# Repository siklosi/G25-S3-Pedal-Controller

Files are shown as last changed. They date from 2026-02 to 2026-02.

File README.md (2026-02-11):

# G25 S3 Pedal Controller

<p align="center">


pedal_final
pedal_final
</p>

A modern ESP32-S3 based USB game controller for Logitech G25 pedals featuring web-based configuration, custom response curves, and profile management.

## ✨ Features

- **USB HID Game Controller** - Works as a native joystick with 3 axes (Gas/Brake/Clutch)
- **Web-Based Configuration** - Modern, responsive interface accessible via WiFi
- **Real-Time Monitoring** - Live pedal position visualization with raw and processed values
- **Live Configuration** - All settings (deadzones, curves, smoothing) are applied instantly in RAM for real-time tuning
- **Persistent Storage** - Explicit "Save to Flash" required to store settings permanently across reboots
- **Custom Response Curves** - 11-point adjustable curves with visual editor
- **Curve Presets** - Linear, Progressive, S-Shape, and Aggressive profiles
- **Custom Curve Slots** - Save up to 4 custom curves per pedal
- **Profile Management** - Save/load complete configurations with device storage
- **Profile Import/Export** - Backup configurations to PC as JSON files
- **Advanced Calibration** - Min/max calibration, deadzone control, axis inversion
- **Smoothing & Limiting** - Configurable output smoothing and ceiling adjustments
- **WiFiManager** - Easy WiFi setup with captive portal
- **WebSocket Live Data** - 20Hz real-time pedal data streaming

## 🛠️ Hardware Requirements

### ESP32-S3 Board
- **Board**: ESP32-S3-DevKitC-1 (or compatible)
- **Flash**: 8MB minimum (N8 or N16 variants) with custom partition table
- **PSRAM**: Optional (not required for this project)
- **USB**: Native USB support required

### Hall Effect Sensors
- **Type**: Analog hall effect sensors (e.g., SS49E, A3144, or similar)
- **Quantity**: 3 sensors (one per pedal)
- **Output**: Analog voltage output (0-3.3V)

### Wiring
Connect hall sensors to the following GPIO pins:

| Pedal | GPIO Pin | Color Code (Typical) |
|---|---|---|
| Throttle| GPIO 4 | Green |
| Brake | GPIO 5 | Red |
| Clutch  | GPIO 6 | Blue |

**Power Supply:**
- Sensor VCC → 3.3V
- Sensor GND → GND
- Sensor OUT → GPIO pins above

## 📋 Software Requirements

### PlatformIO
This project uses PlatformIO for building and uploading firmware.

**Install PlatformIO:**
```bash
# VS Code Extension (recommended)
# Install PlatformIO IDE extension from VS Code marketplace

# Or CLI
pip install platformio
```

### Dependencies
All dependencies are managed automatically via `platformio.ini`:
- ArduinoJson 6.21.3
- WebSockets 2.4.1
- WiFiManager 2.0.17
- Joystick_ESP32S2 0.9.4

## 🚀 Installation

### 1. Clone Repository
```bash
git clone https://github.com/yourusername/g25-s3-pedals.git
cd g25-s3-pedals
```

### 2. Upload Filesystem (Web Interface)
```bash
# Upload LittleFS filesystem containing web interface
pio run --target uploadfs
```

### 3. Build and Upload Firmware
```bash
# Build and upload firmware
pio run --target upload
```

### 4. Monitor Serial Output
```bash
# View serial output for debugging
pio device monitor
```

## 📡 WiFi Setup

### First-Time Setup
1. **Power on the ESP32-S3** - It will create a WiFi access point
2. **Connect to AP** - Network name: `G25_S3_Pedals`
3. **Configure WiFi** - Your device should open a captive portal automatically
   - If not, navigate to `192.168.4.1`
4. **Enter credentials** - Select your WiFi network and enter password
5. **Connect** - Device will restart and connect to your network

### Finding Device IP
Check serial monitor output after boot:
```
WiFi Connected!
IP: 192.168.1.xxx
```

Or check your router's DHCP client list for "G25_S3_Pedals"

## 🎮 Usage

### Accessing Web Interface

1. Open browser and navigate to: `http://[ESP32_IP_ADDRESS]`
2. You should see the G25 S3 configuration interface
3. WebSocket connection indicator should show "Connected" (green dot)

### Calibration

#### Quick Calibration
1. **Release all pedals** completely
2. Click **Min** button for each pedal
3. **Press each pedal fully**
4. Click **Max** button for each pedal
5. **IMPORTANT:** Click **Save All to Flash** to perform a permanent save. Live changes are RAM-only.

#### Advanced Options
- **Inverted** - Reverse pedal direction if sensor is mounted backwards
- **Deadzones** - Set start/end deadzones to eliminate jitter
  - *Start*: Adds margin to Min value (ignores initial press)
  - *End*: Subtracts margin from Max value (reaches 100% earlier)
- **Smoothing** - Apply exponential smoothing (0-95%)
- **Output Limit** - Cap maximum output (useful for brake pedal)

### Response Curves

#### Curve Editor
- Click directly on the chart to adjust curve points
- 11 adjustable points from 0% to 100% input
- Real-time preview with live pedal position indicator (red dot) that follows the curve

#### Presets
- **Linear** - 1:1 response (default)
- **Progressive** - Gradual increase, sensitive at start
- **S-Shape** - Smooth acceleration/deceleration
- **Aggressive** - Quick response, less precision

#### Custom Curves
1. Adjust curve to your preference
2. **Hold Shift + Click** "Custom X" button to save
3. Click button (without Shift) to load saved curve
4. Up to 4 custom curves per pedal

### Profile Management

#### Device Profiles (Stored on ESP32)
- **Save** - Enter name and click "Save" to store current configuration
- **Load** - Select profile from list and click "Load Selected"
- **Delete** - Select profile and click "Delete"

#### PC Backup/Restore
- **Export File** - Download current configuration as JSON
- **Import File** - Upload previously exported configuration

### Testing in Games

1. **Windows**: Device appears as "Custom Sim - G25 S3 Pedals"
2. **Check Device Manager** → Human Interface Devices
3. **Test in Game Controller Settings**:
   - Right-click Start → Settings → Devices → Printers & Scanners
   - Or search "Set up USB game controllers"
4. **Verify axes**:
   - X-Axis: Throttle
   - Y-Axis: Brake
   - Z-Axis: Clutch

## 🔧 Configuration Details

### Curve Format
Curves are stored as 11-point arrays representing output values (0-100%) at input positions (0%, 10%, 20%...100%).

Example linear curve:
```json
[0, 10, 20, 30, 40, 50, 60, 70, 80, 90, 100]
```

Example progressive curve:
```json
[0, 1, 4, 9, 16, 25, 36, 49, 64, 81, 100]
```

### Configuration File Structure
```json
{
  "gas": {
    "min": 200,
    "max": 3900,
    "dzStart": 10,
    "dzEnd": 10,
    "inverted": false,
    "smooth": 20,
    "ceil": 100,
    "curve": [0, 10, 20, 30, 40, 50, 60, 70, 80, 90, 100]
  },
  "brake": { ... },
  "clutch": { ... },
  "customs": [
    [0, 10, 20, ...],  // Custom slot 1
    [0, 5, 15, ...],   // Custom slot 2
    [0, 10, 20, ...],  // Custom slot 3
    [0, 10, 20, ...]   // Custom slot 4
  ]
}
```

### File Locations
- **Active Config**: `/config.json`
- **Web Interface**: `/index.html`
- **Profiles**: `/profiles/*.json`

## 🐛 Troubleshooting

### Device Not Recognized by PC
- **Check USB cable** - Ensure data lines are connected (not charge-only cable)
- **Driver issues** - Windows should auto-install HID drivers
- **Serial output** - Check for "USB Initialized" message
- **Try different port** - Some USB ports may have compatibility issues

### WiFi Connection Issues
- **Reset WiFi settings** - Uncomment `wm.resetSettings()` in code, upload, then comment out again
- **Check serial monitor** - Look for IP address assignment
- **AP mode** - If connection fails, device creates "G25_S3_Pedals" AP

### Web Interface Not Loading
- **Filesystem upload** - Ensure you ran `pio run --target uploadfs`
- **Browser cache** - Try hard refresh (Ctrl+F5) or incognito mode
- **IP address** - Verify correct IP from serial monitor
- **Check LittleFS** - Files should be in `data/` folder before upload

### Erratic Pedal Readings
- **Calibration** - Recalibrate min/max values
- **Wiring** - Check for loose connections or electrical noise
- **Smoothing** - Increase smoothing value (30-50%)
- **Deadzones** - Add small deadzones (5-15) to eliminate jitter

### Configuration Not Saving
- **Flash space** - Ensure 8MB flash is properly configured
- **Serial output** - Look for "Saved!" messages
- **LittleFS** - Check if filesystem initialized correctly
- **Power cycle** - Restart device to verify persistence

## 🔄 Updating Firmware

### Preserve Configuration
Configurations are stored in LittleFS and survive firmware updates (but not filesystem uploads).

```bash
# Update firmware only (keeps config)
pio run --target upload

# Update both firmware and filesystem (erases config)
pio run --target uploadfs
pio run --target upload
```

**Backup before filesystem update:**
1. Export profiles using "Export File" feature
2. Upload new filesystem
3. Import profiles back

## 📊 Technical Specifications

- **ADC Resolution**: 12-bit (0-4095)
- **Output Resolution**: 12-bit (0-4095)
- **Sampling Rate**: ~1000Hz per sensor
- **WebSocket Update Rate**: 20Hz
- **Web Server**: HTTP on port 80
- **WebSocket**: WS on port 81
- **USB VID**: 0x1209
- **USB PID**: 0xABCD

## 🤝 Contributing

Contributions welcome! Please:
1. Fork the repository
2. Create a feature branch (`git checkout -b feature/amazing-feature`)
3. Commit changes (`git commit -m 'Add amazing feature'`)
4. Push to branch (`git push origin feature/amazing-feature`)
5. Open a Pull Request

## 📝 License

This project is licensed under the MIT License - see the [LICENSE](LICENSE) file for details.

## 🙏 Acknowledgments

- **WiFiManager** by tzapu - Simplified WiFi configuration
- **ArduinoJson** by Benoit Blanchon - JSON parsing/serialization
- **WebSockets** by Links2004 - Real-time communication
- **Joystick_ESP32S2** by schnoog - USB HID implementation
- **Chart.js** - Interactive curve visualization

---

**Made with ❤️ for sim racing enthusiasts**

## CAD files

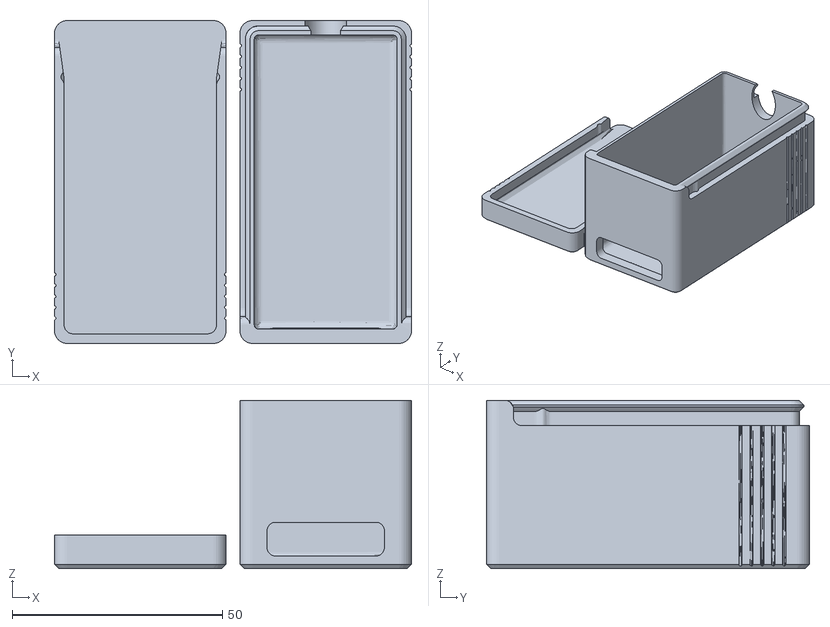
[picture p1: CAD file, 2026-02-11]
3D Parts/G25-S3_MCU_CASE.stl
84.9 x 76.8 x 40.0

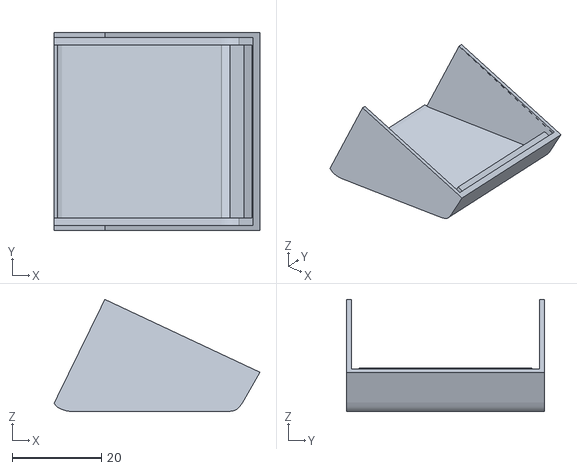
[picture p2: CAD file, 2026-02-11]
3D Parts/Pedal_Cover.stl
46.3 x 44.4 x 25.2

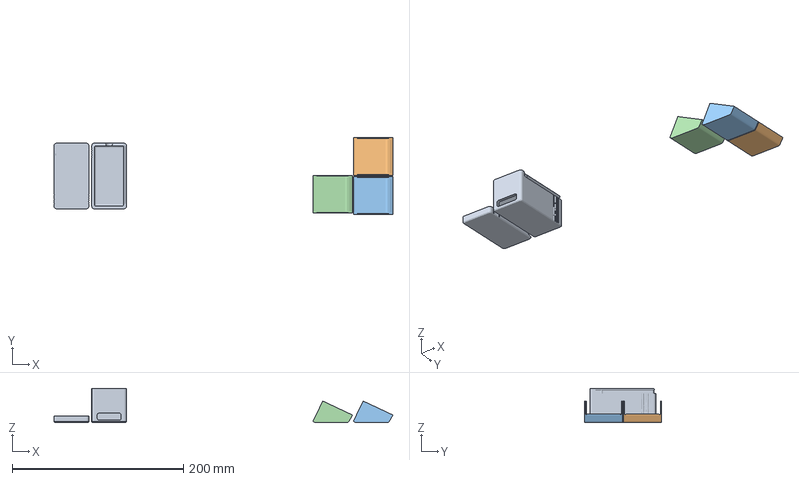
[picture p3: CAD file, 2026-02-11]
3D Parts/G25-S3.3mf
396.4 x 89.8 x 40.0 mm
Amazing Blad-Jaiks.stl
g25_cover.stl x 3

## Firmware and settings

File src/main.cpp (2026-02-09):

#include "Pedal.h"
#include <ArduinoJson.h>
#include <Joystick_ESP32S2.h>
#include <LittleFS.h>
#include <USB.h>
#include <WebServer.h>
#include <WebSocketsServer.h>
#include <WiFiManager.h>

// --- DEFINITIONS ---
#define PIN_GAS 4
#define PIN_BRAKE 5
#define PIN_CLUTCH 6

// --- GLOBALS ---
// 3 Axes (X, Y, Z), 0 buttons, 0 hats
Joystick_ Joystick(JOYSTICK_DEFAULT_REPORT_ID, JOYSTICK_TYPE_JOYSTICK, 0, 0,
                   true, true, true,     // X, Y, Z
                   false, false, false,  // Rx, Ry, Rz
                   false, false,         // Rudder, Throttle
                   false, false, false); // Accelerator, Brake, Steering

String sysLog = "";
void logMsg(String s) {
  sysLog += String(millis()) + ": " + s + "\n";
  // Keep log size reasonable
  if (sysLog.length() > 2048)
    sysLog = sysLog.substring(sysLog.length() - 2048);
  Serial0.println(s);
}

WebServer server(80);
WebSocketsServer webSocket = WebSocketsServer(81);
WiFiManager wm;

// Pedals
Pedal pedalGas(PIN_GAS, 0);
Pedal pedalBrake(PIN_BRAKE, 1);
Pedal pedalClutch(PIN_CLUTCH, 2);

// Threading
TaskHandle_t TaskSensorHandle;
QueueHandle_t qPedalData;

// Output to HID: Verified in TaskSensor
int customCurves[4][11] = {{0, 10, 20, 30, 40, 50, 60, 70, 80, 90, 100},
                           {0, 10, 20, 30, 40, 50, 60, 70, 80, 90, 100},
                           {0, 10, 20, 30, 40, 50, 60, 70, 80, 90, 100},
                           {0, 10, 20, 30, 40, 50, 60, 70, 80, 90, 100}};

struct PedalData {
  int gasRaw, brakeRaw, clutchRaw;
  int gasOut, brakeOut, clutchOut;
};

// WiFi Config
// Managed by WiFiManager

// --- CONFIGURATION ---
// --- CONFIGURATION ---
const char *configPath = "/config.json";
bool fsMounted = false;

// Forward declarations of helper functions
void applyConfigDoc(const StaticJsonDocument<2048> &doc);
void serializeConfigDoc(StaticJsonDocument<2048> &doc);

void loadConfig() {
  if (!fsMounted) {
    logMsg("FS not mounted, skipping loadConfig");
    return;
  }
  if (!LittleFS.exists(configPath)) {
    logMsg("Config file not found: " + String(configPath));
    return;
  }
  File f = LittleFS.open(configPath, "r");
  if (!f) {
    logMsg("Failed to open config file for reading");
    return;
  }

  StaticJsonDocument<2048> doc;
  DeserializationError err = deserializeJson(doc, f);
  f.close();

  if (err) {
    logMsg("JSON Deserialize error: " + String(err.c_str()));
    return;
  }
  logMsg("Config loaded successfully");

  // Load Custom Curves
  JsonArray customs = doc["customs"];
  if (!customs.isNull() && customs.size() == 4) {
    for (int i = 0; i < 4; i++) {
      JsonArray pts = customs[i];
      if (!pts.isNull() && pts.size() == 11) {
        for (int j = 0; j < 11; j++)
          customCurves[i][j] = pts[j];
      }
    }
  }

  // Load Config

  applyConfigDoc(doc);
}

bool saveConfig() {
  if (!fsMounted)
    return false;
  StaticJsonDocument<2048> doc;
  serializeConfigDoc(doc);

  // Verify file open
  File f = LittleFS.open(configPath, "w");
  if (!f) {
    logMsg("FAILED to open config file for writing");
    return false;
  }

  if (serializeJson(doc, f) == 0) {
    logMsg("FAILED to write JSON content");
    f.close();
    return false;
  }

  f.close();
  wm.process(); // Keep WiFi alive

  logMsg("Config saved successfully.");
  return true;
}

// Helper to apply JSON to Pedals
void applyConfigDoc(const StaticJsonDocument<2048> &doc) {
  auto loadOne = [](Pedal &p, JsonVariantConst obj) {
    PedalConfig c = p.getConfig();
    if (obj.containsKey("min"))
      c.min = obj["min"];
    if (obj.containsKey("max"))
      c.max = obj["max"];
    if (obj.containsKey("dzStart"))
      c.deadzoneStart = obj["dzStart"];
    if (obj.containsKey("dzEnd"))
      c.deadzoneEnd = obj["dzEnd"];
    if (obj.containsKey("inverted"))
      c.inverted = obj["inverted"];
    if (obj.containsKey("smooth"))
      c.smoothing = obj["smooth"];
    if (obj.containsKey("ceil"))
      c.outputCeiling = obj["ceil"];
    JsonArrayConst curve = obj["curve"];
    if (!curve.isNull() && curve.size() == 11) {
      for (int i = 0; i < 11; i++)
        c.curvePoints[i] = curve[i];
    }
    p.setConfig(c);
  };
  if (doc.containsKey("gas"))
    loadOne(pedalGas, doc["gas"]);
  if (doc.containsKey("brake"))
    loadOne(pedalBrake, doc["brake"]);
  if (doc.containsKey("clutch"))
    loadOne(pedalClutch, doc["clutch"]);
}

// Helper to serialize Pedals to JSON
void serializeConfigDoc(StaticJsonDocument<2048> &doc) {
  auto saveOne = [](Pedal &p, JsonObject obj) {
    PedalConfig c = p.getConfig();
    obj["min"] = c.min;
    obj["max"] = c.max;
    obj["dzStart"] = c.deadzoneStart;
    obj["dzEnd"] = c.deadzoneEnd;
    obj["inverted"] = c.inverted;
    obj["smooth"] = c.smoothing;
    obj["ceil"] = c.outputCeiling;
    JsonArray curve = obj.createNestedArray("curve");
    for (int i = 0; i < 11; i++)
      curve.add(c.curvePoints[i]);
  };
  saveOne(pedalGas, doc.createNestedObject("gas"));
  saveOne(pedalBrake, doc.createNestedObject("brake"));
  saveOne(pedalClutch, doc.createNestedObject("clutch"));

  JsonArray customs = doc.createNestedArray("customs");
  for (int i = 0; i < 4; i++) {
    JsonArray row = customs.createNestedArray();
    for (int j = 0; j < 11; j++)
      row.add(customCurves[i][j]);
  }
}

// --- TASKS ---
void TaskSensor(void *pvParameters) {
  (void)pvParameters;

  pedalGas.begin();
  pedalBrake.begin();
  pedalClutch.begin();
  // Joystick.begin(); // Moved to setup()

  for (;;) {
    pedalGas.update();
    pedalBrake.update();
    pedalClutch.update();

    Joystick.setXAxis(map(pedalGas.getOutput(), 0, 4095, 0, 1023));
    Joystick.setYAxis(map(pedalBrake.getOutput(), 0, 4095, 0, 1023));
    Joystick.setZAxis(map(pedalClutch.getOutput(), 0, 4095, 0, 1023));
    // Joystick.sendState(); // Auto-send is default in library

    static unsigned long lastUI = 0;
    if (millis() - lastUI > 30) {
      lastUI = millis();
      PedalData d;
      d.gasRaw = pedalGas.getRaw();
      d.brakeRaw = pedalBrake.getRaw();
      d.clutchRaw = pedalClutch.getRaw();
      d.gasOut = pedalGas.getOutput();
      d.brakeOut = pedalBrake.getOutput();
      d.clutchOut = pedalClutch.getOutput();
      xQueueOverwrite(qPedalData, &d);
    }
    vTaskDelay(1);
  }
}

// --- WEB HANDLERS ---
void handleSocket(uint8_t num, WStype_t type, uint8_t *payload, size_t length) {
}

void handleConfigPost() {
  if (server.hasArg("plain")) {
    StaticJsonDocument<2048> doc;
    DeserializationError err = deserializeJson(doc, server.arg("plain"));
    if (err) {
      logMsg("POST JSON Error: " + String(err.c_str()));
      return server.send(400, "text/plain", "JSON Deserialization Failed");
    }

    // Capture debug info before applying
    int debugGasMin = -1;
    if (doc.containsKey("gas") && doc["gas"].containsKey("min")) {
      debugGasMin = doc["gas"]["min"];
    }

    vTaskSuspend(TaskSensorHandle);

    // Save Custom Curves if present
    JsonArray customs = doc["customs"];
    if (!customs.isNull() && customs.size() == 4) {
      for (int i = 0; i < 4; i++) {
        JsonArray pts = customs[i];
        if (!pts.isNull() && pts.size() == 11) {
          for (int j = 0; j < 11; j++)
            customCurves[i][j] = pts[j];
        }
      }
    }

    applyConfigDoc(doc);

    bool persistent = true;
    if (server.hasArg("persistent") && server.arg("persistent") == "false") {
      persistent = false;
    }

    bool saved = true;
    if (persistent) {
      saved = saveConfig();
    }
    vTaskResume(TaskSensorHandle);

    // Construct response
    String resp = "{\"status\":\"";
    resp += (saved ? "ok" : "save_failed");
    resp += "\", \"debug_gas_min\":";
    resp += String(debugGasMin);
    resp += "}";

    server.sendHeader("Cache-Control", "no-cache, no-store, must-revalidate");
    if (saved)
      server.send(200, "application/json", resp);
    else
      server.send(500, "application/json", resp);
  } else {
    server.send(400, "text/plain", "No Body");
  }
}

void handleConfigGet() {
  StaticJsonDocument<2048> doc;
  serializeConfigDoc(doc);
  // Add current IP for UI display
  doc["ip"] = WiFi.localIP().toString();
  doc["uptime"] = millis();

  // Add FS Status
  if (fsMounted) {
    doc["fs_total"] = LittleFS.totalBytes();
    doc["fs_used"] = LittleFS.usedBytes();
    doc["fs_mounted"] = true;
  } else {
    doc["fs_mounted"] = false;
  }

  String out;
  serializeJson(doc, out);
  server.sendHeader("Cache-Control", "no-cache, no-store, must-revalidate");
  server.send(200, "application/json", out);
}

void handleDebug() {
  StaticJsonDocument<4096> doc;
  doc["log"] = sysLog;

  JsonArray files = doc.createNestedArray("files");
  File root = LittleFS.open("/");
  if (root && root.isDirectory()) {
    File f = root.openNextFile();
    while (f) {
      JsonObject fObj = files.createNestedObject();
      fObj["name"] = String(f.name());
      fObj["size"] = f.size();
      fObj["dir"] = f.isDirectory();
      f = root.openNextFile();
    }
  }

  // check profiles subdir
  File pRoot = LittleFS.open("/profiles");
  if (pRoot && pRoot.isDirectory()) {
    File f = pRoot.openNextFile();
    while (f) {
      JsonObject fObj = files.createNestedObject();
      fObj["name"] = "/profiles/" + String(f.name());
      fObj["size"] = f.size();
      f = pRoot.openNextFile();
    }
  }

  String out;
  serializeJson(doc, out);
  server.send(200, "application/json", out);
}

// --- PROFILES API ---
// GET /api/profiles/list
void handleProfilesList() {
  if (!LittleFS.exists("/profiles"))
    LittleFS.mkdir("/profiles");
  File root = LittleFS.open("/profiles");
  if (!root || !root.isDirectory()) {
    server.send(200, "application/json", "[]");
    return;
  }
  StaticJsonDocument<1024> doc;
  JsonArray arr = doc.to<JsonArray>();

  File file = root.openNextFile();
  while (file) {
    String name = file.name();
    if (name.endsWith(".json")) {
      // remove extension for display?
      // name is usually "/profiles/foo.json" or just "foo.json" depending on
      // lib version Let's just send filename
      arr.add(name);
    }
    file = root.openNextFile();
  }
  String out;
  serializeJson(doc, out);
  server.send(200, "application/json", out);
}

// POST /api/profiles/save?name=F1
void handleProfileSave() {
  if (!server.hasArg("name"))
    return server.send(400);
  String name = server.arg("name");
  // sanitize
  name.replace("/", "");
  if (!name.endsWith(".json"))
    name += ".json";
  String path = "/profiles/" + name;

  // Get current config
  StaticJsonDocument<2048> doc;
  serializeConfigDoc(doc);

  File f = LittleFS.open(path, "w");
  if (f) {
    serializeJson(doc, f);
    f.close();
    server.send(200, "application/json", "{\"status\":\"saved\"}");
  } else {
    server.send(500, "application/json", "{\"status\":\"error\"}");
  }
}

// POST /api/profiles/load?name=F1.json
void handleProfileLoad() {
  if (!server.hasArg("name"))
    return server.send(400);
  String name = server.arg("name");
  if (!name.endsWith(".json"))
    name += ".json";
  String path = "/profiles/" + name;

  if (!LittleFS.exists(path))
    return server.send(404);

  File f = LittleFS.open(path, "r");
  if (f) {
    StaticJsonDocument<2048> doc;
    DeserializationError err = deserializeJson(doc, f);
    f.close();
    if (!err) {
      vTaskSuspend(TaskSensorHandle);
      applyConfigDoc(doc);
      saveConfig(); // Persist as active config
      vTaskResume(TaskSensorHandle);
      server.send(200, "application/json", "{\"status\":\"loaded\"}");
      return;
    }
  }
  server.send(500);
}

// POST /api/profiles/delete?name=F1.json
void handleProfileDelete() {
  if (!server.hasArg("name"))
    return server.send(400);
  String name = server.arg("name");
  String path = "/profiles/" + name;
  if (LittleFS.remove(path))
    server.send(200);
  else
    server.send(500);
}

void setup() {
  // Init IO
  Serial0.begin(115200);
  delay(1000); // Give serial time to wake up
  Serial0.println("\n\n=== FIRMWARE BOOT START ===");

  // Init USB immediately so it enumerates before WiFi blocks
  logMsg("Initializing USB...");
  USB.begin();
  Joystick.setXAxisRange(0, 1023);
  Joystick.setYAxisRange(0, 1023);
  Joystick.setZAxisRange(0, 1023);
  Joystick.begin();
  logMsg("USB Initialized.");

  if (LittleFS.begin(true)) {
    fsMounted = true;
    logMsg("LittleFS Mount Success");
    logMsg("Total Bytes: " + String(LittleFS.totalBytes()));
    logMsg("Used Bytes: " + String(LittleFS.usedBytes()));
  } else {
    fsMounted = false;
    logMsg("LittleFS Mount FAILED");
  }

  if (!LittleFS.exists("/profiles")) {
    LittleFS.mkdir("/profiles");
    logMsg("Created /profiles dir");
  }

  loadConfig();

  qPedalData = xQueueCreate(1, sizeof(PedalData));

  xTaskCreatePinnedToCore(TaskSensor, "SensorTask", 4096, NULL, 1,
                          &TaskSensorHandle, 1);

  // WiFi Setup
  // WiFi Setup (WiFiManager)
  // wm.resetSettings(); // Unlock if you need to wipe during dev

  // Set non-blocking if we want pedals to work during partial connection fail,
  // but for initial setup, blocking is safer to guarantee IP.
  // We'll trust autoConnect to handle it.
  wm.setAPCallback([](WiFiManager *myWiFiManager) {
    Serial0.println("Entered config mode");
    Serial0.println(WiFi.softAPIP());
    Serial0.println(myWiFiManager->getConfigPortalSSID());
  });

  bool res = wm.autoConnect("G25_S3_Pedals");

  if (!res) {
    Serial0.println("Failed to connect");
    // ESP.restart();
  } else {
    Serial0.println("WiFi Connected!");
    Serial0.print("IP: ");
    Serial0.println(WiFi.localIP());
  }

  // Explicitly handle root to ensure index.html is served
  server.on("/", HTTP_GET, []() {
    File file = LittleFS.open("/index.html", "r");
    if (!file) {
      server.send(404, "text/plain", "File Not Found");
      return;
    }
    server.streamFile(file, "text/html");
    file.close();
  });

  server.on("/api/config", HTTP_POST, handleConfigPost);
  server.on("/api/config", HTTP_GET, handleConfigGet);
  // Profiles
  server.on("/api/profiles/list", HTTP_GET, handleProfilesList);
  server.on("/api/profiles/save", HTTP_POST, handleProfileSave);
  server.on("/api/profiles/load", HTTP_POST, handleProfileLoad);
  server.on("/api/profiles/delete", HTTP_POST, handleProfileDelete);
  server.on("/api/debug", HTTP_GET, handleDebug);

  // Serve static files last
  server.serveStatic("/", LittleFS, "/");

  server.begin();
  webSocket.begin();
  webSocket.onEvent(handleSocket);
}

void loop() {
  server.handleClient();
  webSocket.loop();

  static unsigned long lastBroadcast = 0;
  if (millis() - lastBroadcast > 50) {
    lastBroadcast = millis();
    PedalData d;
    if (xQueuePeek(qPedalData, &d, 0)) {
      String json = "{";
      json += "\"gas\":{\"r\":" + String(d.gasRaw) +
              ",\"o\":" + String(d.gasOut) + "},";
      json += "\"brake\":{\"r\":" + String(d.brakeRaw) +
              ",\"o\":" + String(d.brakeOut) + "},";
      json += "\"clutch\":{\"r\":" + String(d.clutchRaw) +
              ",\"o\":" + String(d.clutchOut) + "}";
      json += "}";
      webSocket.broadcastTXT(json);
    }
  }
}

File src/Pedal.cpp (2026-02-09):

#include "Pedal.h"

Pedal::Pedal(int pin, int id) : _pin(pin), _id(id) {}

void Pedal::begin() {
  pinMode(_pin, INPUT);
  // ESP32-S3 ADC is 12-bit by default (0-4095)
  // We can use analogReadResolution if needed, but default is usually 12
  analogReadResolution(12);
}

void Pedal::update() {
  // 1. Oversampling / Reading
  long sum = 0;
  int samples = 16;
  for (int i = 0; i < samples; i++) {
    sum += analogRead(_pin);
  }
  int rawAvg = sum / samples;
  // Revert to inverted reading as requested
  _currentRaw = 4095 - rawAvg;

  // 2. Normalize to Config Min/Max (0.0 - 1.0)
  // Determine actual effective range handling min > max (reverse pot)

  int start, end;
  bool isReversed = _config.min > _config.max;

  int clampedRaw = _currentRaw;

  if (isReversed) {
    start = _config.min - _config.deadzoneStart;
    end = _config.max + _config.deadzoneEnd;
    // Clamp
    if (clampedRaw > start)
      clampedRaw = start;
    if (clampedRaw < end)
      clampedRaw = end;
  } else {
    start = _config.min + _config.deadzoneStart;
    end = _config.max - _config.deadzoneEnd;
    // Clamp
    if (clampedRaw < start)
      clampedRaw = start;
    if (clampedRaw > end)
      clampedRaw = end;
  }

  // Protect against zero range
  if (start == end)
    end = start + 1;

  // 3. Map to 0-1000 (0.0% to 100.0%) for Curve lookup
  // map() handles start > end correctly
  long inputScaled = map(clampedRaw, start, end, 0, 1000);

  // Constrain just in case map extrapolates due to weird bounds (though we
  // clamped raw above)
  inputScaled = constrain(inputScaled, 0, 1000);

  if (_config.inverted) {
    inputScaled = 1000 - inputScaled;
  }

  // 4. Apply Curve
  // Curve points are 0..100 percentages. We interpolate between them.
  // curvePoints has 11 entries: 0%, 10%, ... 100% input

  int index = inputScaled / 100;
  int remainder = inputScaled % 100;

  if (index >= 10) {
    // 100% input case
    index = 9;
    remainder = 100;
  }

  int p1 = _config.curvePoints[index];
  int p2 = _config.curvePoints[index + 1];

  float valP1 = p1;
  float valP2 = p2;

  float interpolated = valP1 + ((valP2 - valP1) * (remainder / 100.0f));

  // interpolated is 0.0 - 100.0 (percentage)

  // 5. Apply Output Ceiling
  // If outputCeiling is 80, we scale 0-100 to 0-80? Or do we clip?
  // "Limiter" usually means clip, but for racing, re-scaling range is often
  // better so you still have full pedal travel. However, brake limit usually
  // means "I press 100% physically but game sees 80%". Wait, usually it's "I
  // want 100% game signal at 80% pressure". That's what calibration Min/Max is
  // for. "Output Limiter" as requested (cap max output) usually means "Don't
  // ever send more than 80% to game". This is useful if a car locks up easily.
  // So we Clip or Rescale. Let's CLIP. If result > ceiling, result = ceiling.
  if (interpolated > _config.outputCeiling)
    interpolated = (float)_config.outputCeiling;

  // 6. Scale to Final Output 0-4095
  float targetOutput = interpolated * 40.95f;

  // 7. Apply Smoothing (Low Pass Filter)
  // _config.smoothing is 0-99.
  // alpha = 1.0 means no filtering (take new value). alpha = 0.01 means mostly
  // old value. Map smoothing 0 (alpha 1.0) -> 90 (alpha 0.1) -> 99 (alpha 0.01)

  float alpha = 1.0f;
  if (_config.smoothing > 0) {
    // Simple mapping: alpha = 1.0 - (smoothing / 100.0)
    // if smoothing 90, alpha = 0.1
    // if smoothing 0, alpha = 1.0
    // Limit max smoothing to prevent freeze
    int s = constrain(_config.smoothing, 0, 98);
    alpha = 1.0f - (s / 100.0f);
  }

  // Initialize if first run or huge jump? No, standard EMA
  _filteredValue = (_filteredValue * (1.0f - alpha)) + (targetOutput * alpha);

  _currentOutput = (int)_filteredValue;
}

int Pedal::getOutput() { return _currentOutput; }

int Pedal::getRaw() { return _currentRaw; }

void Pedal::setConfig(PedalConfig config) {
  bool wasInv = _config.inverted;
  _config = config;
  // reset filter if needed? usually fine not to.
}

PedalConfig Pedal::getConfig() { return _config; }

void Pedal::calibrateMin() { _config.min = _currentRaw; }

void Pedal::calibrateMax() { _config.max = _currentRaw; }

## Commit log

2026-02-09 Revise GPIO pin assignments and save instructions
    Updated README to reflect changes in GPIO pin assignments and added important notes for saving settings.
2026-02-09 Update Pedal class to handle inverted readings
    Revert raw reading for inverted pedals and adjust normalization logic for reversed configurations.
    [Pedal.cpp]
2026-02-11 3D Parts
    [G25-S3.3mf, G25-S3_MCU_CASE.stl, Pedal_Cover.stl]
